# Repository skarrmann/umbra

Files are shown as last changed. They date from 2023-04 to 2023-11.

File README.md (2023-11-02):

# Umbra Keyboard

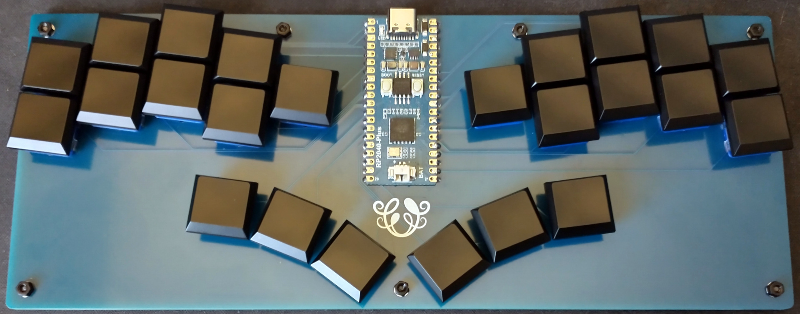
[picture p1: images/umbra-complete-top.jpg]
Umbra complete build top photo


Umbra is a 24 key ergonomic keyboard, powered by a Raspberry Pi Pico.

There are enough keys for playing many games with a keyboard. 2D fighting games like Street Fighter was my personal intent for this build.

The board is a simple rectangle for increased sturdiness, which helps when placing the keyboard on your lap.

## Project structure

* [`gerbers`](gerbers): Gerber files for PCB manufacturing
* [`graphics`](graphics): Source assets for PCB silkscreen
* [`kicad`](kicad): KiCad project files (schematics and PCB designs)
* [`kicad-libraries`](kicad-libraries): KiCad components and footprints
* [`images`](images): Images for project documentation
* [`firmware`](firmware): Firmware files

## PCB

The PCB is designed for Kailh Choc v1 keyswitches, and supports keycaps designed for 18mm x 17mm spacing.

The Pi Pico footprint uses surface-mount solder pads. The castellated pads of the Pi Pico are used to solder it directly to the PCB.

The keyswitches are directly connected to the GPIO pins of the Pi Pico.

Each build uses two copies of the same PCB. This PCB acts as both the logical PCB, and when flipped the long way, it acts as a bottom plate to be attached the logical PCB.

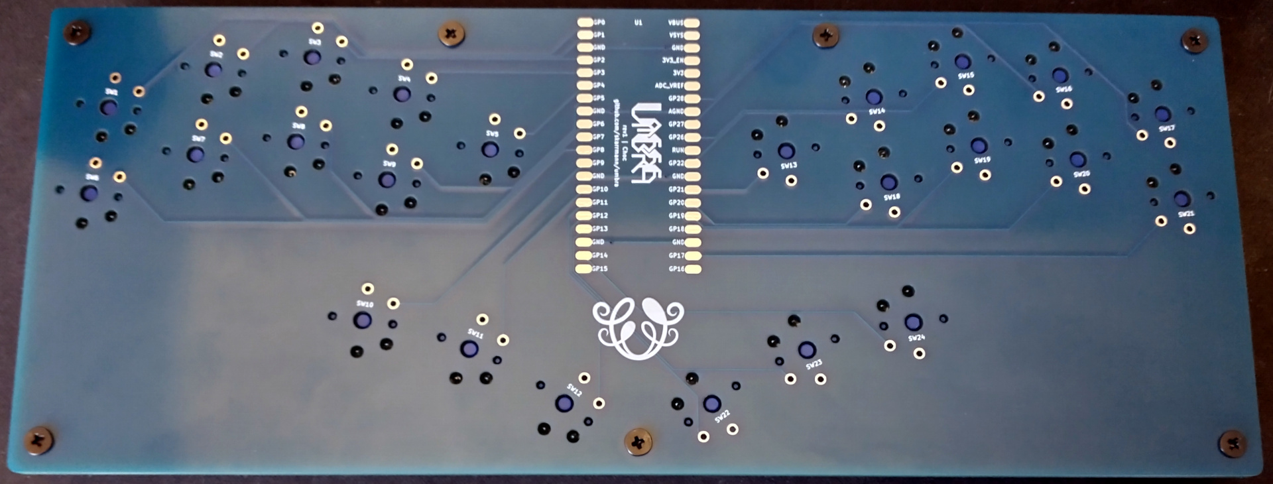
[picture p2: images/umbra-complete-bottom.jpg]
Umbra complete build bottom photo

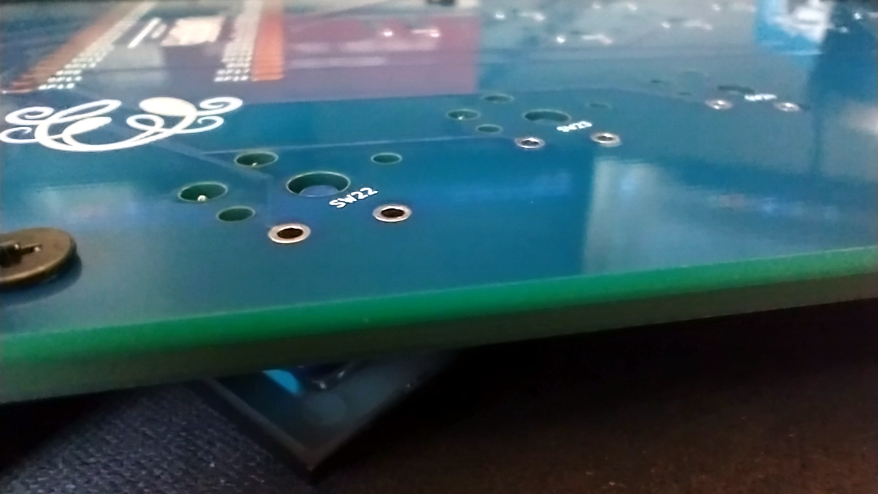
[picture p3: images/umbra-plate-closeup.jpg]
Umbra plate closeup


## Keyboard firmware

* KMK
    * Setup instructions and basic configuration is in this repo: [`firmware/kmk`](firmware/kmk)
* GP2040-CE
    * Setup instructions in this repo: [`firmware/gp2040-ce`](firmware/gp2040-ce)

## Bill of materials

Part | Purpose | Quantity | Notes
---- | ------- | -------- | ---------
PCB  | circuit board and bottom plate | 2 | Send Gerber zip files to [JLCPCB](https://jlcpcb.com/).
Raspberry Pi Pico | Microcontroller board | 1 | Supports other boards with the Pico footprint and castellated solder pads (Waveshare RP2040 Plus) 
Keyswitches |  | 24 | Kailh Choc V1 keyswitches
Keycaps |  | 24 | Kailh Choc V1 keycaps (18mm x 17mm)
M2 6mm screws | Secure main PCB and bottom plate PCB | 7 |
M2 nuts | Secure main PCB and bottom plate PCB | 7 |
2mm tall rubber bumpons | Raise board above desk surface and provide skid resitance | 8 |

## PCB manufacturing settings

These are the manufacturing settings I used when ordering from JLCPCB:

* **Base Material**: FR4
* **Layers**: 2
* **Dimensions**: (whatever the gerber file specifies)
* **PCB Qty**: 5
* **Different Design**: 1
* **Delivery Format**: Single PCB
* **PCB Thickness**: 1.6
* **PCB Color**: Blue
* **Silkscreen**: White
* **Surface Finish**: LeadFree HASL-RoHS
* **Outer Copper Weight**: 1 oz
* **Gold Fingers**: No
* **Confirm Production File**: No
* **Flying Probe Test**: Fully Test
* **Castellated Holes**: No
* **Remove Order Number**: Specify a location

**IMPORTANT:** The PCB has ["JLCJLCJLCJLC" silkscreen text](https://support.jlcpcb.com/article/28-how-to-remove-order-number-from-your-pcb) on the bottom side of the board. If you want to remove the order number from the boards or you want to print the PCBs with another manufacturer, then I recommend removing this silkscreen text from the `.kicad_pcb` file, and then regenerate the Gerber files.

## Build tips

* Before starting, check if the PCBs are warped, and bend them to be perfectly flat before soldering.
* To secure the bottom plate PCB, you can use flat metal M2 screws instead. Or use double-sided tape to adhere the bottom plate PCB directly to the logical PCB.

## KiCad project notes

The keyswitch footprints have cutouts for their through-hole solder pads, rotated 180 degrees from the center of the footprint. On opposite halves of the PCB, the keyswitch footprints are rotated 180 degrees. This allows the cutouts to encase the solder pads when the PCB is flipped and used as a bottom plate.

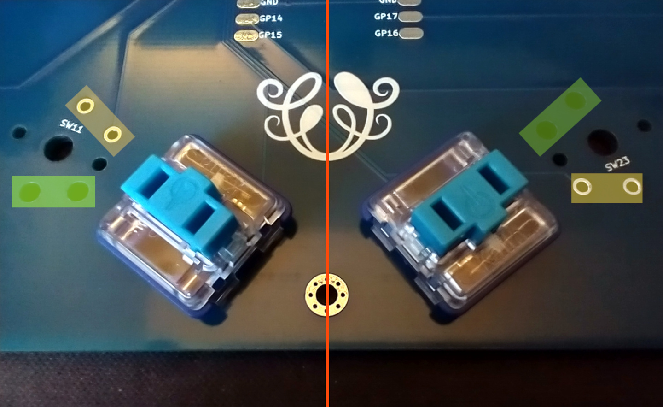
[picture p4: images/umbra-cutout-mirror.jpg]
Umbra cutout mirror


This project contains KiCad footprints for both Choc and MX switches with these mounting cutouts. There are also footprints and symbols for other microcontroller boards with castellated pads considered for the design (Waveshare RP-2040 Zero and Seeed XIAO RP2040).

Here are guidelines for using Umbra's self-encasing PCB construction approach for your own designs:

* Choose a microcontroller board which has castellated pads. Place the microcontroller footprint at the exact center of the PCB.
    * If the microcontroller board has components soldered to its bottom side (e.g., the Waveshare RP2040 Zero), then make a cutout on the PCB in the space between the solder pads of the microcontroller board's footprint.
* Place keyswitches on the left and right sides of the board so they are perfectly symmetric with each other. On the right side of the board, rotate each keyswitch 180 degrees.
* Make the board's edge cuts perfectly symmetric the long way. Rectangles are cool, but so are curvy shapes that trace the contours of the keyswitches!

## Revision history

* Choc rev1 (2022-03-19)
    * Initial PCB design

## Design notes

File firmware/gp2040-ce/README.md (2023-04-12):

# Umbra GP2040-CE Configuration

Follow the [installation instructions at the GP2040-CE Firmware documentation](https://gp2040-ce.info/#/?id=installation).

Once the GP2040-CE firmware has been flashed onto the Pi Pico, configure the board with the [GP2040 Web Configurator](https://gp2040.info/#/web-configurator). In the initial firmware, the `S2` key is mapped to `GP17`, which is the furthest right bottom key on the Umbra. So to activate the web configurator, hold this key when plugging in the board.

In the GP2040 Configurator, apply the configuration:

1. In **Configuration > Pin Mapping**, set your preferred pin mapping. Here is the Umbra Pi Pico GPIO pin assignment:
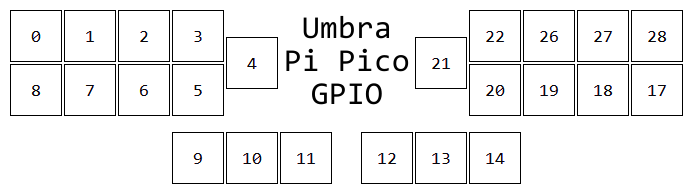
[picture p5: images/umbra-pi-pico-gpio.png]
Umbra Pi Pico GPIO
    
2. In **Configuration > LED Configuration**, set "Data Pin" to `-1` and click **Save**.
3. (Optional) In **Configuration > Add Ons**, disable all options and click **Save**.
4. Once done, click **Reboot**.

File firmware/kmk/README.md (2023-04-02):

# Umbra KMK Firmware

## Installation instructions

1. Install CircuitPython:
    * https://circuitpython.org/board/raspberry_pi_pico/
2. Copy KMK firmware files:
    * https://github.com/KMKfw/kmk_firmware/blob/master/docs/Getting_Started.md
3. Copy the custom files:
    * [`kb.py`](kb.py)
    * [`main.py`](main.py)

Now customize the layout and features in [`main.py`](main.py) file, and save the updates on your board.

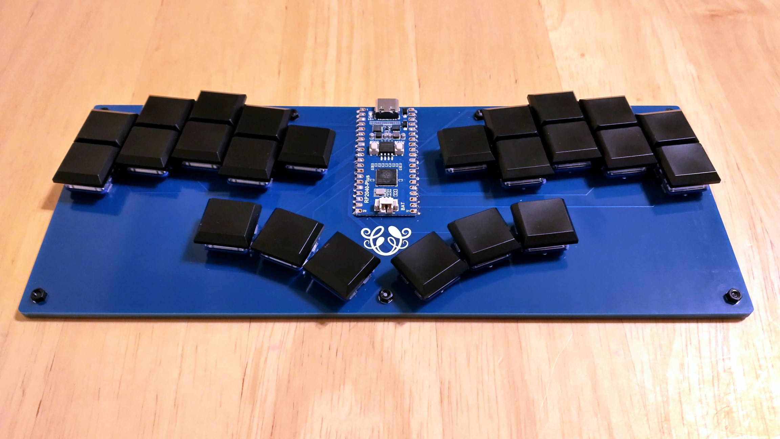
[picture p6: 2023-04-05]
images/umbra-complete-top-16-9.jpg

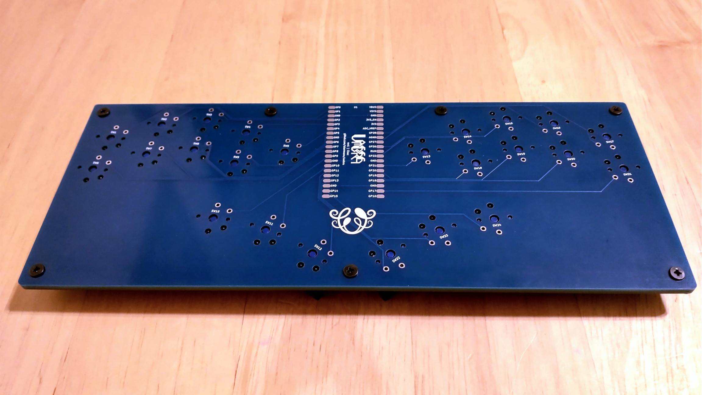
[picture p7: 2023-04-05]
images/umbra-complete-bottom-16-9.jpg

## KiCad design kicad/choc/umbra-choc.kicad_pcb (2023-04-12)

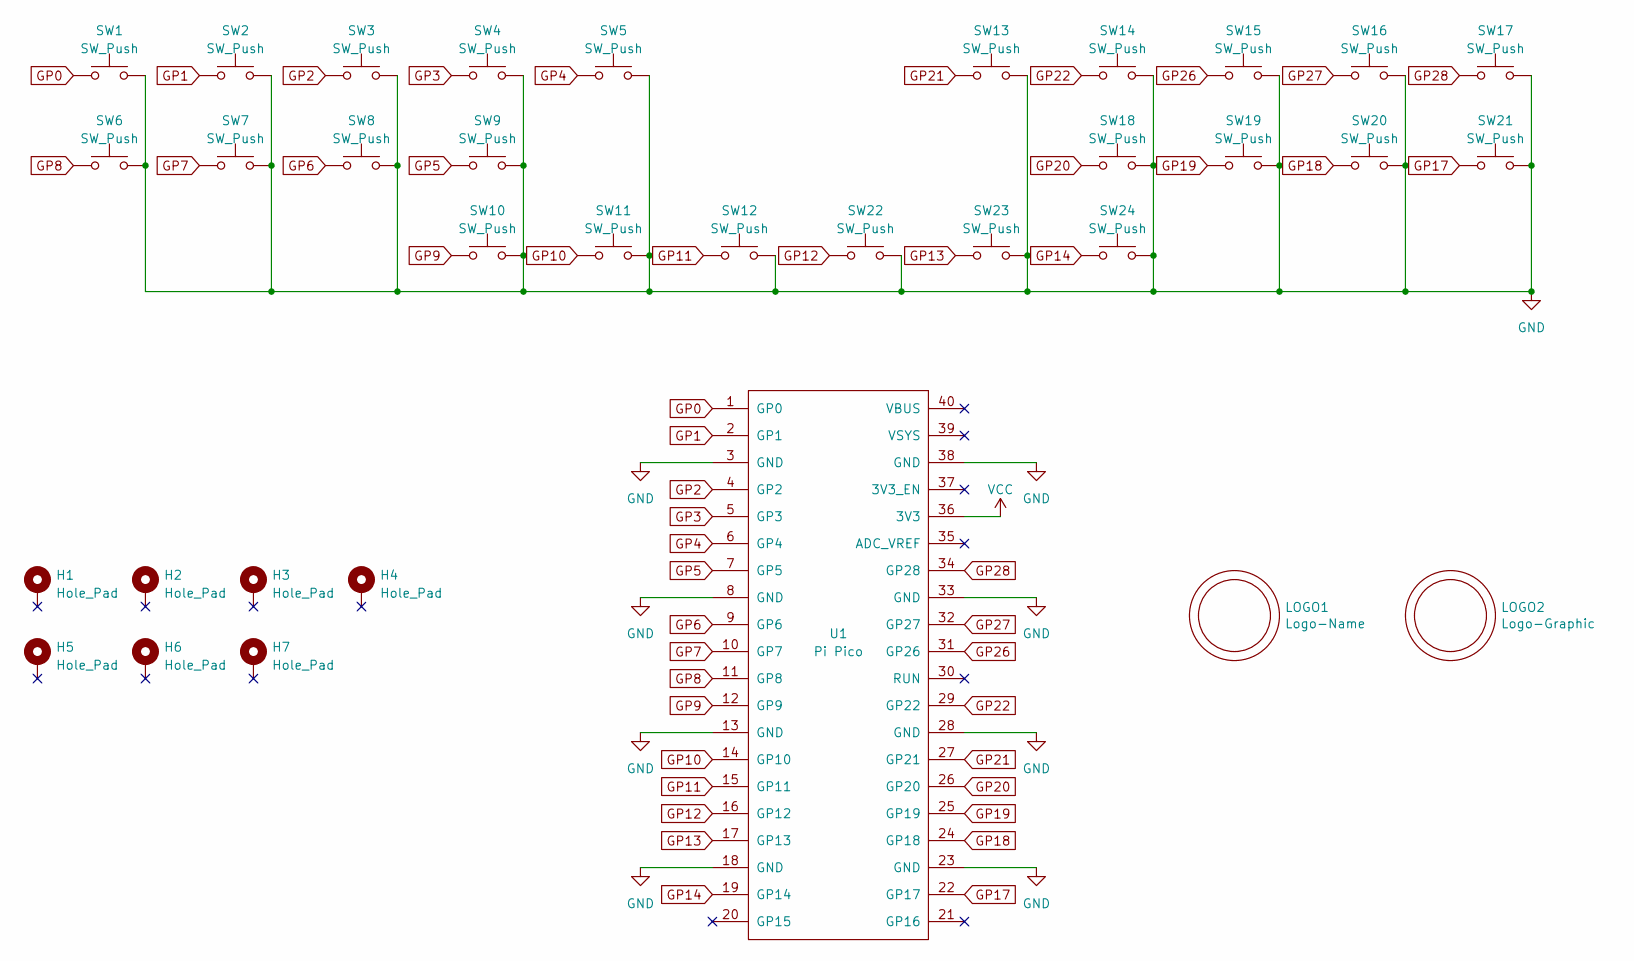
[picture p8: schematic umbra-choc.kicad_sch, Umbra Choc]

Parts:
H1, H2, H3, H4, H5, H6, H7: Hole_Pad; Mount_M2
LOGO1: Logo-Name; Logo_Umbra_Name
LOGO2: Logo-Graphic; Logo_Umbra
SW1, SW2, SW3, SW4, SW5, SW6, SW7, SW8, SW9, SW10, SW11, SW12, SW13, SW14, SW15, SW16, SW17, SW18, SW19, SW20, SW21, SW22, SW23, SW24: SW_Push; SW_Choc_Reverse_Cutout
U1: Pi Pico; Pi-Pico_SMD

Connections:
GND: SW1.2, SW2.2, SW3.2, SW4.2, SW5.2, SW6.2, SW7.2, SW8.2, SW9.2, SW10.2, SW11.2, SW12.2, SW13.2, SW14.2, SW15.2, SW16.2, SW17.2, SW18.2, SW19.2, SW20.2, SW21.2, SW22.2, SW23.2, SW24.2, U1.3 (GND), U1.8 (GND), U1.13 (GND), U1.18 (GND), U1.23 (GND), U1.28 (GND), U1.33 (GND), U1.38 (GND)
GP0: SW1.1, U1.1 (GP0)
GP1: SW2.1, U1.2 (GP1)
GP2: SW3.1, U1.4 (GP2)
GP3: SW4.1, U1.5 (GP3)
GP4: SW5.1, U1.6 (GP4)
GP5: SW9.1, U1.7 (GP5)
GP6: SW8.1, U1.9 (GP6)
GP7: SW7.1, U1.10 (GP7)
GP8: SW6.1, U1.11 (GP8)
GP9: SW10.1, U1.12 (GP9)
GP10: SW11.1, U1.14 (GP10)
GP11: SW12.1, U1.15 (GP11)
GP12: SW22.1, U1.16 (GP12)
GP13: SW23.1, U1.17 (GP13)
GP14: SW24.1, U1.19 (GP14)
GP17: SW21.1, U1.22 (GP17)
GP18: SW20.1, U1.24 (GP18)
GP19: SW19.1, U1.25 (GP19)
GP20: SW18.1, U1.26 (GP20)
GP21: SW13.1, U1.27 (GP21)
GP22: SW14.1, U1.29 (GP22)
GP26: SW15.1, U1.31 (GP26)
GP27: SW16.1, U1.32 (GP27)
GP28: SW17.1, U1.34 (GP28)
VCC: U1.36 (3V3)

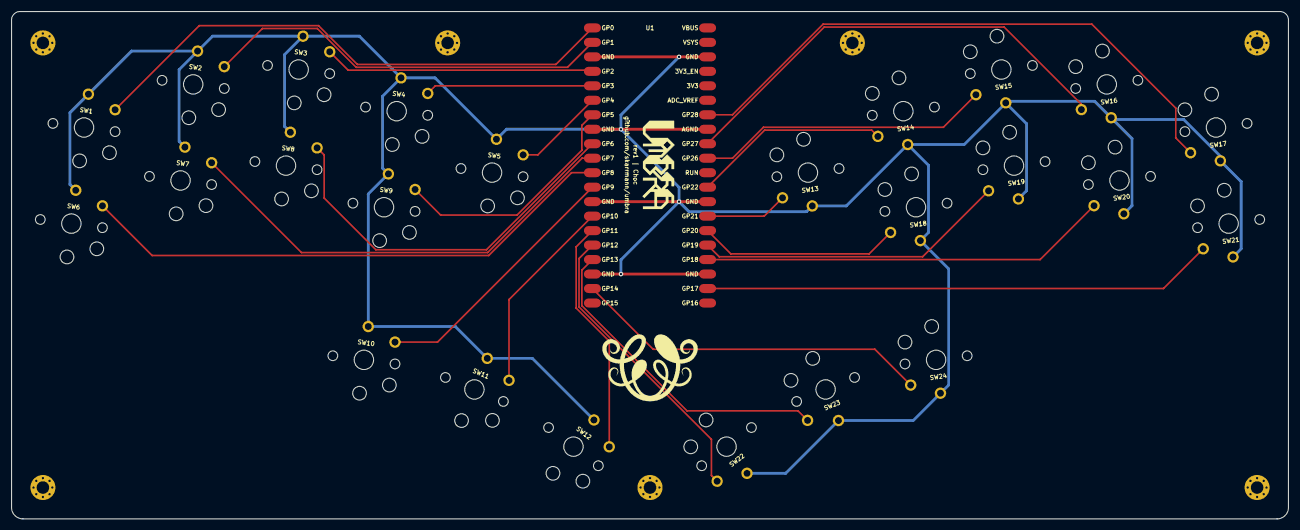
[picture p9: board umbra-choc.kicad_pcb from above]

Board: 2 copper layers, 224.0 x 89.0 mm, 34 parts (0 on the bottom side), 25 nets.

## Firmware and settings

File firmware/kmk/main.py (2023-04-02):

from kb import KMKKeyboard

from kmk.keys import KC
from kmk.modules.layers import Layers

keyboard = KMKKeyboard()

layers_ext = Layers()

keyboard.modules = [layers_ext]

P1 = KC.DF(0)
P2 = KC.DF(1)
FUN = KC.MO(2)

keyboard.keymap = [
    [ # Player 1
        KC.A   , KC.B   , KC.C   , KC.D   , KC.E   ,                   KC.F   , KC.G   , KC.H   , KC.I   , KC.J   ,
        KC.K   , KC.L   , KC.M   , KC.N   ,                                     KC.O   , KC.P   , KC.Q   , KC.R   ,
                                   KC.S   , KC.T   , KC.U   , KC.V   , KC.W   , FUN    ,
    ],
    [ # Player 2
        KC.N1  , KC.N2  , KC.N3  , KC.N4  , KC.N5  ,                   KC.N6  , KC.N7  , KC.N8  , KC.N9  , KC.N0  ,
        KC.LEFT, KC.DOWN, KC.UP  , KC.RGHT,                                     KC.COMM, KC.DOT , KC.MINS, KC.EQL ,
                                   KC.QUOT, KC.LBRC, KC.RBRC, KC.BSLS, KC.SLSH, FUN    ,
    ],
    [ # Function
        KC.NO  , KC.NO  , KC.NO  , KC.NO  , P1     ,                   P2     , KC.NO  , KC.NO  , KC.NO  , KC.NO  ,
        KC.NO  , KC.NO  , KC.NO  , KC.NO  ,                                     KC.NO  , KC.NO  , KC.NO  , KC.NO  ,
                                   KC.NO  , KC.NO  , KC.NO  , KC.NO  , KC.NO  , FUN    ,
    ],
]

if __name__ == '__main__':
    keyboard.go()

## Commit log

2023-03-20 Create Choc rev1
    [umbra-choc.kicad_pcb, umbra-choc.kicad_sch]
2023-04-12 Update schematic global labels for GPIO assignment readability
    [umbra-choc.kicad_pcb, umbra-choc.kicad_sch]
